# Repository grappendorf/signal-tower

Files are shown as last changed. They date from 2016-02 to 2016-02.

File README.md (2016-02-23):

# Signal Tower

Signal towers (or stack lights) are usually used in industrial manufacturing and display the
state of a machine to the operators. They are mounted on a pole, which makes it easy to spot a
malfunctioning machine from far away. Different colors can be used to display various conditions
(for example green = normal, red = malfunction, yellow = warning, blue = good, but low on raw
materials).

Nowadays software development is also partly regarded as an industrial process. For example
continuous integration and deployment can be fully automated. When a developer pushes new code into
the central repository, this code can be automatically build, tested and deployed onto production
servers. Testing is an essential part of this process, since you don't want bad code to creep into
production.

A fast feedback of these problems to the developers helps them to quickly react accordingly. So
today more and more development teams are installing some kind of easily perceptible
good/broken-indicators. This can either be a big monitor which displays some kind of a build
status dashboard, or a stylish industrial signal tower like the one in the picture above.

This a custom shield for an Arduino which can control three signal tower lights. It is accessable
via WLAN and the firmware implements a small HTTP server, which allows you to control the signal
tower through some simple HTTP-REST-APIs.

[Read more about this project on my website...](http://www.grappendorf.net/projects/signal-tower.html)

# Build

This project is powered by [PlatformIO](http://platformio.org/#!/)

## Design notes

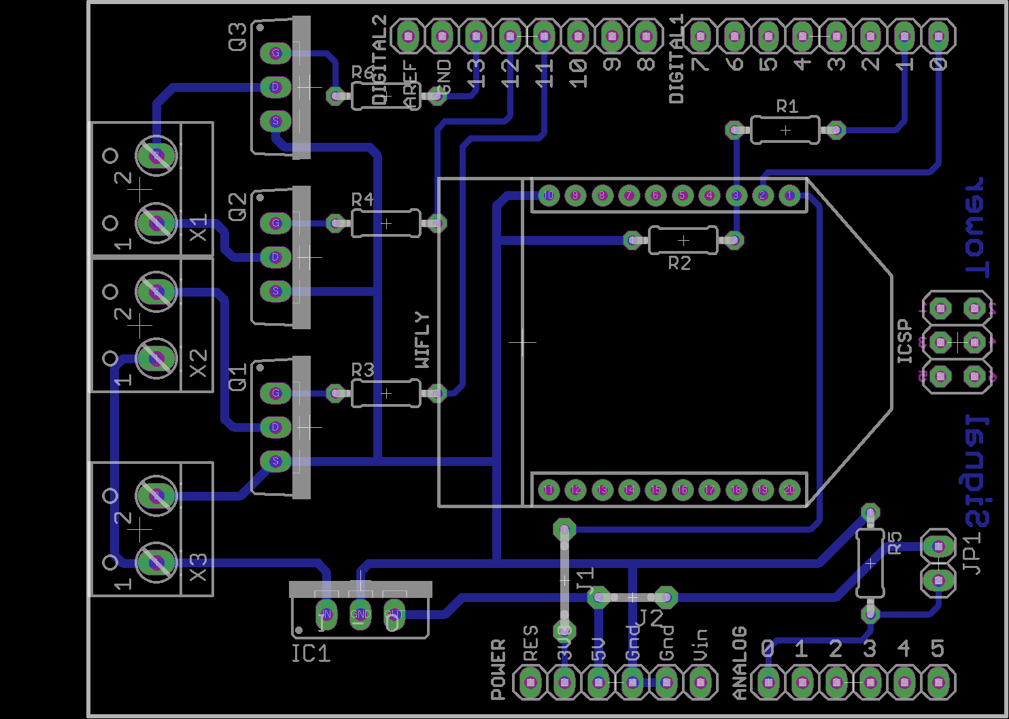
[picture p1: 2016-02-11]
eagle/signal-tower-brd.png

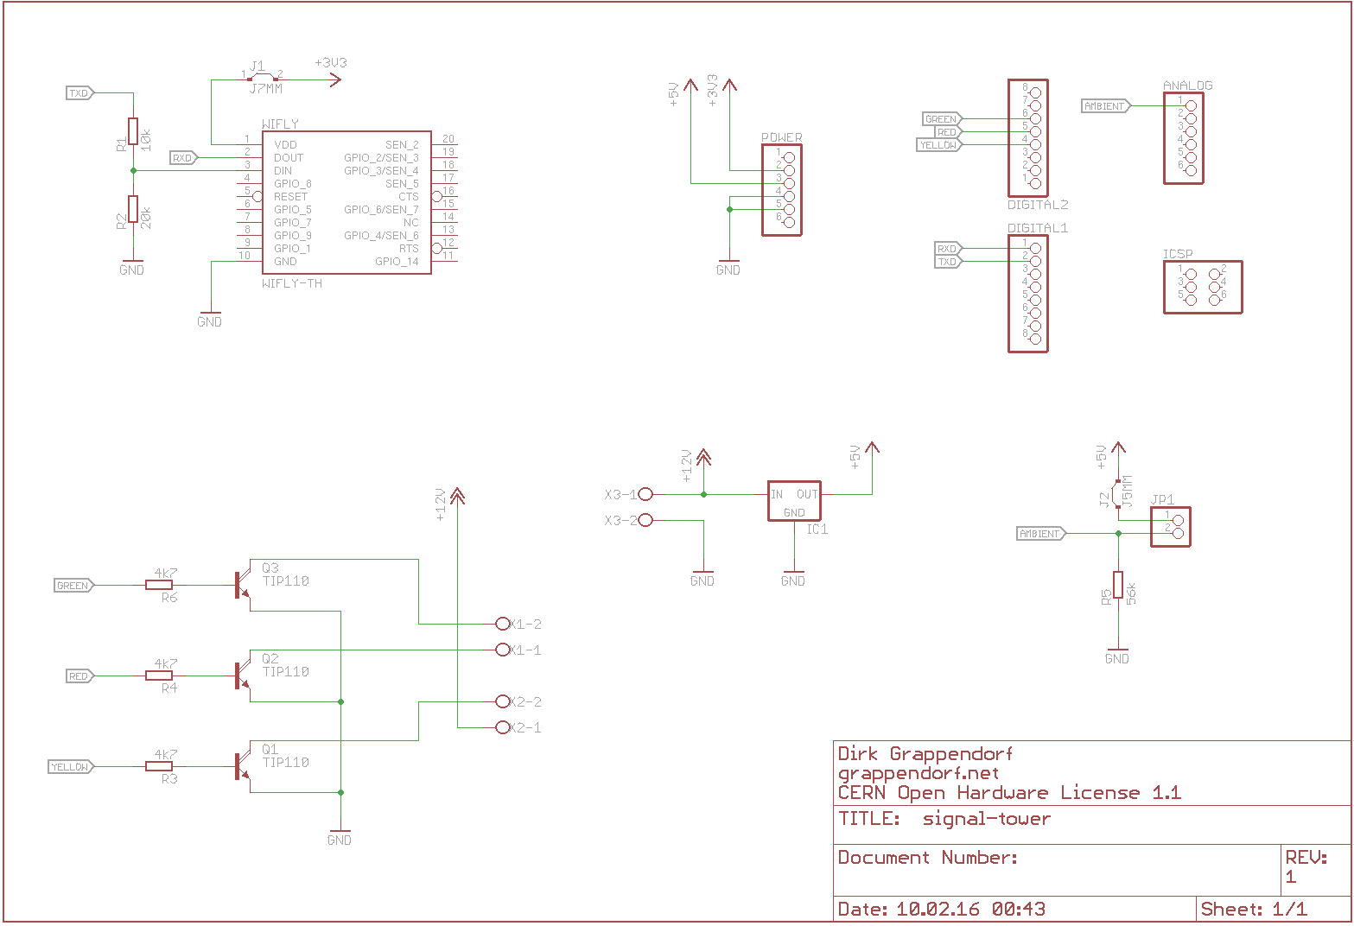
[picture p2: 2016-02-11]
eagle/signal-tower-sch.png

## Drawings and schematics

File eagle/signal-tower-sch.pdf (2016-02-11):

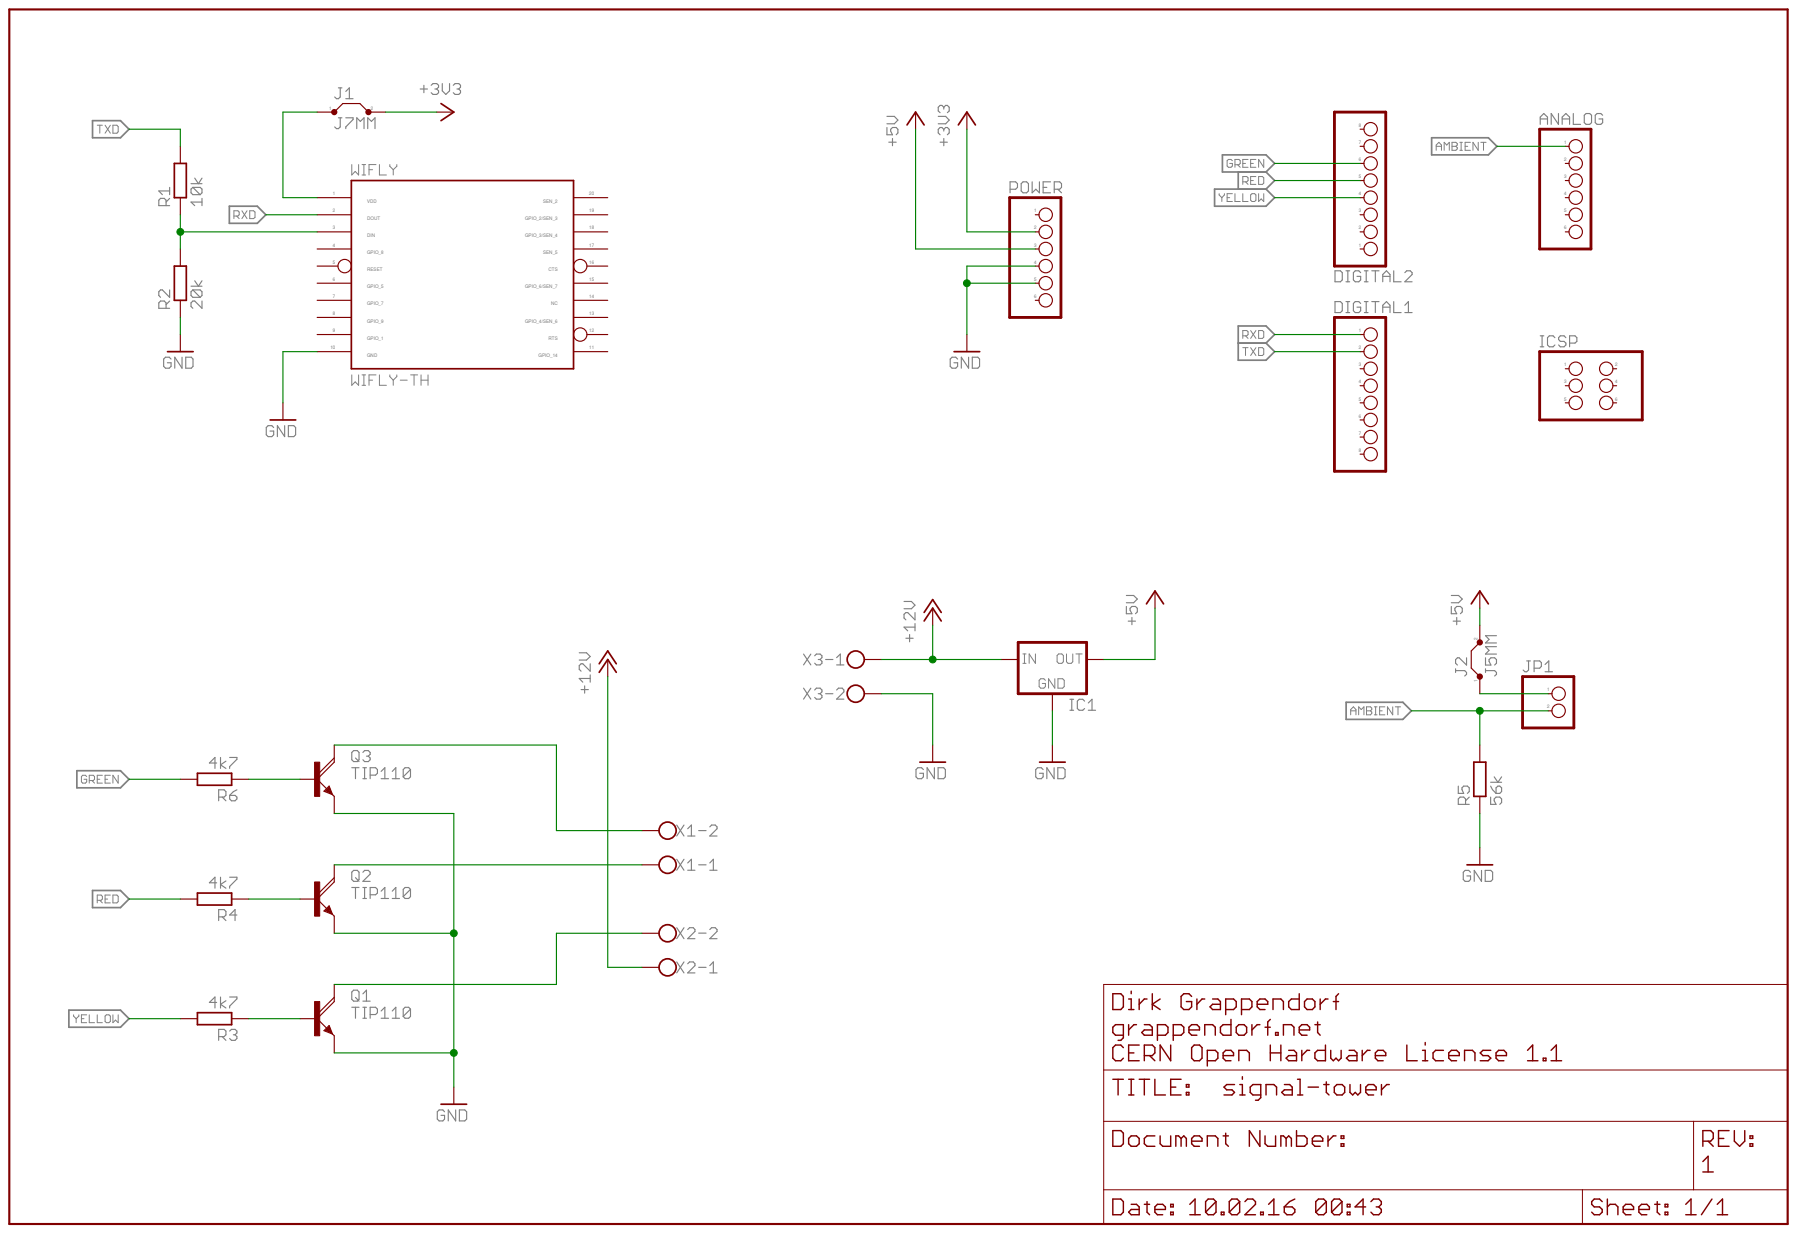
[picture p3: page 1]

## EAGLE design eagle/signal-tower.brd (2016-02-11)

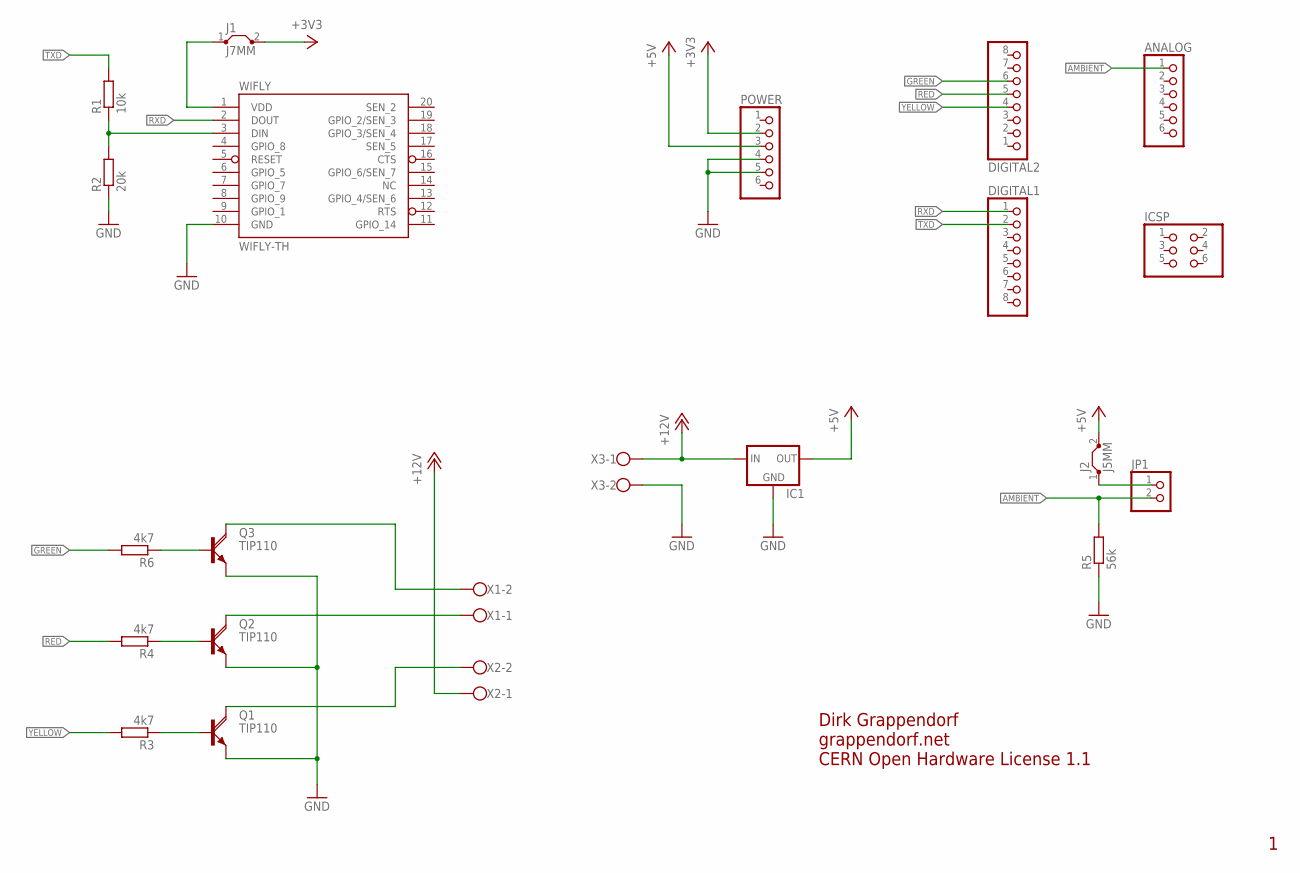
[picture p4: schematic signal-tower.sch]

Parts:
ANALOG: PINHD-1X6; 1X06
DIGITAL1: PINHD-1X8TH; 1X08-TH
DIGITAL2: PINHD-1X8_2.54; 1X08
IC1: 78XXS
ICSP: PINHD-2X3; 2X03
J1: J7MM; 07
J2: J5MM; 05
JP1: PINHD-1X2; 1X02
POWER: PINHD-1X6_2.54; 1X06
Q1, Q2, Q3: TIP110; TO220BV
R1: 10k; 0204/7
R2: 20k; 0204/7
R3, R4, R6: 4k7; 0204/7
R5: 56k; 0204/7
WIFLY: WIFLY-TH
X1, X2, X3: W237-102

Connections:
+3V3: J1.2, POWER.2
+5V: IC1.OUT, J2.2, POWER.3
+12V: IC1.IN, X2.1, X3.1
AMBIENT: ANALOG.1, JP1.2, R5.2
GND: IC1.GND, POWER.4, POWER.5, Q1.S (E), Q2.S (E), Q3.S (E), R2.1, R5.1, WIFLY.10 (GND), X3.2
GREEN: DIGITAL2.6, R6.2
unnamed: R1.1, R2.2, WIFLY.3 (DIN)
unnamed: Q3.D (C), X1.2
unnamed: J1.1, WIFLY.1 (VDD)
unnamed: Q1.G (B), R3.1
unnamed: Q2.G (B), R4.1
unnamed: Q3.G (B), R6.1
unnamed: Q2.D (C), X1.1
unnamed: Q1.D (C), X2.2
unnamed: J2.1, JP1.1
RED: DIGITAL2.5, R4.2
RXD: DIGITAL1.1, WIFLY.2 (DOUT)
TXD: DIGITAL1.2, R1.2
YELLOW: DIGITAL2.4, R3.2

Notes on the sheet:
Dirk Grappendorf
grappendorf.net
CERN Open Hardware License 1.1

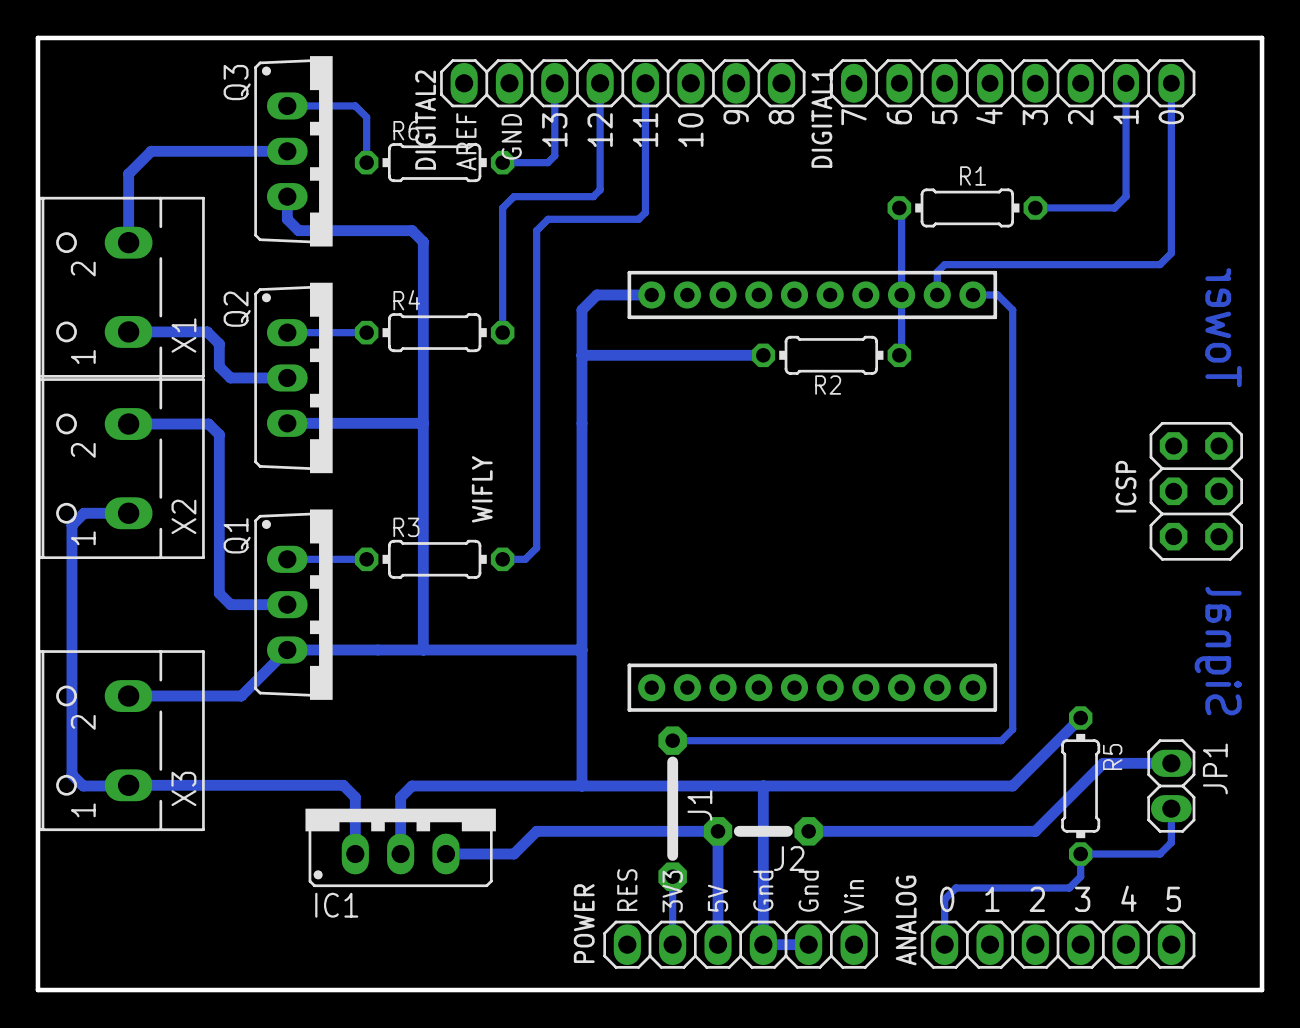
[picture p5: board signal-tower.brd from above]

Board: 2 copper layers, 68.6 x 53.3 mm, 22 parts (0 on the bottom side), 19 nets.

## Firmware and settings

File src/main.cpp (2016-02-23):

/**
 * This file is part of the signal-tower firmware.
 *
 * (c) 2016 Dirk Grappendorf (www.grappendorf.net)
 */

#include <Arduino.h>
#include <ArduinoJson.h>
#include <EEPROMex.h>
#include <avr/wdt.h>

const uint8_t PIN_GREEN = 13;
const uint8_t PIN_RED = 12;
const uint8_t PIN_YELLOW = 11;
const uint8_t PIN_AMBIENT = A0;

bool green;
bool red;
bool yellow;
bool mute;
int ambient;
unsigned long green_timeout = 0;
unsigned long red_timeout = 0;
unsigned long yellow_timeout = 0;

uint16_t magic;
uint8_t threshold;
uint8_t hysteresis;
const uint16_t MAGIC_NUMBER = 0xCAFE;
const uint8_t DEFAULT_THRESHOLD = 100;
const uint8_t DEFAULT_HYSTERESIS = 5;
const uint16_t EEPROM_SIZE = EEPROMSizeATmega328;
const uint16_t EEPROM_MAGIC_ADDR = 0;
const uint16_t EEPROM_THRESHOLD_ADDR = (EEPROM_MAGIC_ADDR + sizeof(magic));
const uint16_t EEPROM_HYSTERESIS_ADDR = (EEPROM_THRESHOLD_ADDR + sizeof(hysteresis));

enum Method {
  GET, PUT
};
int contentLength;
Method method;
String path;

const int BUFFER_LENGTH = 200;
char buffer[BUFFER_LENGTH + 1];

void readEeprom();
void updateLeds();
void checkLedTimeouts();
void processSensors();
void getSensors();
void getLeds();
void putLeds();
void getSettings();
void putSettings();
void selfTest();
void parseHttp();
String parsePath(String line);
String readContent();
void sendResponse(int status, String content);
void sendResponse(int status, JsonObject &content);
void sendResponse(int status);

void setup() {
  EEPROM.setMemPool(0, EEPROM_SIZE);
  readEeprom();

  pinMode(PIN_GREEN, OUTPUT);
  pinMode(PIN_RED, OUTPUT);
  pinMode(PIN_YELLOW, OUTPUT);

  green = false;
  red = false;
  yellow = false;
  mute = false;
  contentLength = 0;

  selfTest();
  updateLeds();
  Serial.begin(57600);
  wdt_enable(WDTO_4S);
}

void loop() {
  wdt_reset();

  if (Serial.available()) {
    parseHttp();
  }

  processSensors();
  checkLedTimeouts();
}

void readEeprom() {
  magic = EEPROM.readInt(EEPROM_MAGIC_ADDR);
  if (magic != MAGIC_NUMBER) {
    EEPROM.writeInt(EEPROM_MAGIC_ADDR, MAGIC_NUMBER);
    hysteresis = DEFAULT_HYSTERESIS;
    EEPROM.writeBlock(EEPROM_THRESHOLD_ADDR, &threshold, sizeof(threshold));
    threshold = DEFAULT_THRESHOLD;
    EEPROM.writeBlock(EEPROM_HYSTERESIS_ADDR, &hysteresis, sizeof(hysteresis));
  } else {
    EEPROM.readBlock(EEPROM_THRESHOLD_ADDR, &threshold, sizeof(threshold));
    EEPROM.readBlock(EEPROM_HYSTERESIS_ADDR, &hysteresis, sizeof(hysteresis));
  }
}

void updateLeds() {
  digitalWrite(PIN_GREEN, (green && !mute) ? HIGH : LOW);
  digitalWrite(PIN_RED, (red && !mute) ? HIGH : LOW);
  digitalWrite(PIN_YELLOW, (yellow && !mute) ? HIGH : LOW);
}

void checkLedTimeouts() {
  if (green_timeout != 0 && millis() > green_timeout) {
    green = false;
    green_timeout = 0;
    updateLeds();
  }
  if (red_timeout != 0 && millis() > red_timeout) {
    red = false;
    red_timeout = 0;
    updateLeds();
  }
  if (yellow_timeout != 0 && millis() > yellow_timeout) {
    yellow = false;
    yellow_timeout = 0;
    updateLeds();
  }
}

void processSensors() {
  ambient = (int) map(analogRead(PIN_AMBIENT), 0, 1023, 0, 255);
  if (mute && ambient > threshold + hysteresis) {
    mute = false;
    updateLeds();
  } else if (!mute && ambient < threshold - hysteresis) {
    mute = true;
    updateLeds();
  }
}

void getSensors() {
  StaticJsonBuffer<BUFFER_LENGTH + 1> jsonBuffer;
  JsonObject &json = jsonBuffer.createObject();
  json["ambient"] = ambient;
  sendResponse(200, json);
}

void getLeds() {
  StaticJsonBuffer<BUFFER_LENGTH + 1> jsonBuffer;
  JsonObject &json = jsonBuffer.createObject();
  json["green"] = green;
  json["yellow"] = yellow;
  json["red"] = red;
  json["muted"] = mute;
  if (green_timeout > 0) {
    json["green_duration"] = (green_timeout - millis()) / 1000;
  }
  if (red_timeout > 0) {
    json["red_duration"] = (red_timeout - millis()) / 1000;
  }
  if (yellow_timeout > 0) {
    json["yellow_duration"] = (yellow_timeout - millis()) / 1000;
  }
  sendResponse(200, json);
}

void putLeds() {
  String content = readContent();
  StaticJsonBuffer<BUFFER_LENGTH + 1> jsonBuffer;
  JsonObject &json = jsonBuffer.parseObject(content);
  if (json.success()) {
    if (json.containsKey("green")) {
      green = json["green"];
    }
    if (json.containsKey("green_duration") && json["green_duration"] > 0) {
      green_timeout = millis() + (int) json["green_duration"] * 1000;
      green_timeout = max(green_timeout, 1);
    }
    if (json.containsKey("red")) {
      red = json["red"];
    }
    if (json.containsKey("red_duration") && json["red_duration"] > 0) {
      red_timeout = millis() + (int) json["red_duration"] * 1000;
      red_timeout = max(red_timeout, 1);
    }
    if (json.containsKey("yellow")) {
      yellow = json["yellow"];
    }
    if (json.containsKey("yellow_duration") && json["yellow_duration"] > 0) {
      yellow_timeout = millis() + (int) json["yellow_duration"] * 1000;
      yellow_timeout = max(yellow_timeout, 1);
    }
    updateLeds();
    sendResponse(204);
  } else {
    sendResponse(400);
  }
}

void getSettings() {
  StaticJsonBuffer<BUFFER_LENGTH + 1> jsonBuffer;
  JsonObject &json = jsonBuffer.createObject();
  json["threshold"] = threshold;
  json["hysteresis"] = hysteresis;
  sendResponse(200, json);
}

void putSettings() {
  String content = readContent();
  StaticJsonBuffer<BUFFER_LENGTH + 1> jsonBuffer;
  JsonObject &json = jsonBuffer.parseObject(content);
  if (json.success()) {
    if (json.containsKey("threshold")) {
      threshold = max(0, min(255, json["threshold"]));
      EEPROM.writeBlock(EEPROM_THRESHOLD_ADDR, &threshold, sizeof(threshold));
    }
    if (json.containsKey("hysteresis")) {
      hysteresis = max(0, min(255, json["hysteresis"]));
      EEPROM.writeBlock(EEPROM_HYSTERESIS_ADDR, &hysteresis, sizeof(hysteresis));
    }
    sendResponse(204);
  } else {
    sendResponse(400);
  }
}

void selfTest() {
  for (int i = 0; i < 4; ++i) {
    digitalWrite(PIN_GREEN, HIGH);
    delay(200);
    digitalWrite(PIN_GREEN, LOW);
    digitalWrite(PIN_YELLOW, HIGH);
    delay(200);
    digitalWrite(PIN_YELLOW, LOW);
    digitalWrite(PIN_RED, HIGH);
    delay(200);
    digitalWrite(PIN_RED, LOW);
  }
}

void parseHttp() {
  String line = Serial.readStringUntil('\n');
  if (line.startsWith("Content-Length: ")) {
    sscanf(line.c_str() + 16, "%d", &contentLength);
  } else if (line.startsWith("GET")) {
    method = GET;
    path = parsePath(line);
  } else if (line.startsWith("PUT")) {
    method = PUT;
    path = parsePath(line);
  } else if (line == "\r") {
    if (path.startsWith("/reset")) {
      sendResponse(200);
      setup();
    } else if (path.startsWith("/sensors") && method == GET) {
      getSensors();
    } else if (path.startsWith("/leds") && (method == GET)) {
      getLeds();
    } else if (path.startsWith("/leds") && (method == PUT)) {
      putLeds();
    } else if (path.startsWith("/settings") && (method == GET)) {
      getSettings();
    } else if (path.startsWith("/settings") && (method == PUT)) {
      putSettings();
    } else {
      sendResponse(404);
    }
    contentLength = 0;
  }
}

String parsePath(String line) {
  int firstPathChar = line.indexOf(' ') + 1;
  int nextPathChar = line.indexOf(' ', (unsigned int) firstPathChar);
  if (nextPathChar == -1) {
    nextPathChar = line.length();
  }
  return line.substring((unsigned int) firstPathChar, (unsigned int) nextPathChar);
}

String readContent() {
  Serial.readBytes(buffer, (size_t) min(contentLength, BUFFER_LENGTH));
  return String(buffer);
}

void sendResponse(int status, String content) {
  Serial.print("HTTP/1.1 ");
  Serial.println(status);
  Serial.println("Connection: close");
  Serial.print("Content-Length: ");
  Serial.println(content.length());
  Serial.println("Content-Type: application/json");
  Serial.println();
  if (content.length() > 0) {
    Serial.println(content);
  }
}

void sendResponse(int status, JsonObject &content) {
  String responseString;
  content.printTo(responseString);
  sendResponse(status, responseString);
}

void sendResponse(int status) {
  sendResponse(status, "");
}
